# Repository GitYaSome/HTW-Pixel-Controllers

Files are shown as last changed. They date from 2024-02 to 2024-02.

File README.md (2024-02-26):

# HTW Pixel Controllers



I originally wanted to create these controllers as a gift for my fellow Warriors so that every HTW participant in any parade or night ride could have a high-quality set of LED lights.  On February 5th, 2024 I found out about Terry Sague being hit and killed by a car.  Other cyclists he was with were hospitalized.  That was yet another reason to get these done sooner rather than later.

Basic Use:
1.	Plug USB cord into trike battery or USB Powerbank.
2.	Press the power switch on the side of the USB Powerbank.
3.	Turn on the controller via the toggle switch. (It will default to 4th of July / Red, White, and Blue)
4.	Select a preset by pressing preset button – I programmed 5 presets into them:

a)	4th of July – Red, White, & Blue – (Default when the controller is turned on)
b)	Christmas – Red & Green
c)	Multicolor – Multicolor cycle – Alternate for Christmas
d)	Night Ride – Red, White, & Orange
e)	Maintenance – All White – Use for fixing something on your trike in the dark.

Notes:
1.	Unfortunately, the power switches I got from China are not as moisture proof as I thought and can get oxidation on the contacts.  If after doing steps 1-3 above the controller does not turn on, rapidly turn the power switch on and off about 10-20 times to clean the contacts.  (I added 2 silica gel packs to the 3D printed cases and used form-a-gasket to seal the lids on, so hopefully this won’t be an issue.)
2.	The white USB-A to USB-C cable in the accessory bag is to charge the USB Powerbanks.  The USB-C connectors on the USB Powerbanks are VERY delicate – PLEASE BE VERY CAREFUL INSERTING AND REMOVING THOSE CABLES.
In case anyone ever needs to make more or needs to troubleshoot, etc..

1.	3D Printed Case design files
2.	Circuit board schematics, Pick&Place, Gerber Files, & BOM
3.	Parts lists
4.	Extra Pictures

I hope you enjoy using these as much as I enjoyed making them for you – Have fun!!!
-Kevin Cook

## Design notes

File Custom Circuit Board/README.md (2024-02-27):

There are 3 files in this folder:
  1. BOM_HTW WLED PCB_2023-12-21.csv - This is the Bill of Materials file that contains part numbers for the assembly service to know what parts are needed.
  2. Gerber_HTW WLED PCB.zip - This is the file that has the board dimensions, locations of holes to be drilled, and schematic diagram. 
  3. PickAndPlace_HTW WLED PCB_2023-12-21.csv - This is the file that tells the assembly service the X and Y coordinates of where to place parts.

Those 3 files are what you would send to a Printed Circuit Board manufacturer (I use JLCPCB) to have PCB's made.
In addition to those 3 files, here are some pictures:

Schematic Diagram:


Circuit Board Layout:
Circuit Board Layout

Circuit Board Front View:
Circuit Board Front View

Circuit Board Rear View:
Circuit Board Rear View

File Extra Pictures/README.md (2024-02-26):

Extra Pictures:

Original prototype on a breadboard (This was mostly to test the level shifter):


From prototype to custom circuit board (Not all parts are soldered on here yet, but you get the idea):


ESP32 Microcontrollers ready to be flashed (Programmed):


Some 3D Printed cases:


Some 3D Printed Lids and Tube Mounts:


Lids done:


3d Printed Inserts:                                                


3D printed Lids with RED, White, and Blue inserts:


3D Printed End Caps for the Pixel Strings:                                                 


Waterproofing backs of inserts with liquid electrical tape:


Backs sealed up, ready for assembly:


Close up of some of the parts:


Getting there!:


A completed controller:


Form-a-gasket around the inner rim and all 4 screw posts:


2 packs of Silica Gel in each case:


Lid ready for bolts:


Red, White, and Blue Zipties inserted:


Ready for burn in test!


Burn in test:




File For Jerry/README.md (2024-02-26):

The controllers can all work in multiple ways:

1. 100% Stand Alone - Everyone responsible for their own.
   Each person will turn their controller on and select a preset.

2. Jerry Controls everyone via handheld remote.
   If there are about 12 controllers or less (We can test this in real world conditions once handed out) you can use the Wiz remote to turn everyone on / off and select 1 of the first 4 presets.
   Note - This is a software on / off - They will still all have to have their power swithches set to On at their individual controllers.

3. More than 12 riders via the Wiz remote or if you want to use the WLED App.
   Pack the included Wi-Fi router with you, and turn it on.  Then have each rider turn their controller on - They will all connect to this router and your controller is set to be the master controller - Whatever you do on yours, theirs will sync to it.
   Note - Your controller is HTW01 and has a special yellow heat shrink on the data cable to help differentiate it from the others.

4. If you are ever asked fo any password on the router or in the WLED app, the password is Warr10r5!

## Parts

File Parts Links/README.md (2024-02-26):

Parts Links:

50 Strand Bullet Pixels:
No mater where you buy them or what spacing you use, make sure you get WS281x, 5VDC, xConnect pinout (Many different pinouts are out there and if you put voltage into the data line, at a minimum you will kill the first pixel and have to cut it out and splice the cuts.) I ordered 2 strands of 50 for each controller with 6 inch spacing.



  https://www.aliexpress.us/item/3256805872144854.html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 (RayWu is a great seller - I used him for thousands of strands of lights when I did my Christmas light shows.)

USB Powerbank:
  https://www.amazon.com/gp/product/B07XFBN7HX/ref=ppx_yo_dt_b_search_asin_title?ie=UTF8&th=1

PG-11 Cable Glands:
  https://www.aliexpress.us/item/2255800056118195.html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

Stainless Steel Bolts:
  https://www.aliexpress.us/item/3256801789306671.html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

200cm USB Power Cables:
  https://www.aliexpress.us/item/3256805002233217.html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

Pixel Connector Cables:
  https://www.holidaycoro.com/EasyPlug3-Female-Pigtail-Dangle-xConnect-p/723-f.htm 

Switches:

MTS-202 Power Switches:
  https://www.aliexpress.us/item/2255800227673206.html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

Preset Select:
  https://www.aliexpress.us/item/3256802598843527.html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

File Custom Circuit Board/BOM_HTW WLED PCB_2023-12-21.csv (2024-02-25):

ID | Name | Designator | Footprint | Quantity | Manufacturer Part | Manufacturer | Supplier | Supplier Part | Price | Pins | 3DModel | Contributor | JLCPCB Part Class | Resistance (Ohms) | link
1 | HEADER - 2.54_1X5 | H1,H2 | HEADER-HEADER-FEMALE-2.54_1X5 | 2 |  |  |  |  |  | 5 |  | feelafter
2 | HEADER-1X2 FAN | X2,X1 | HEADER-1X2-2.54 | 2 |  |  | Mouser | undefined |  | 2 |  | sfzhi
3 | 4.7kΩ | R2,R3 | R0603 | 2 | 0603WAF4701T5E | UNI-ROYAL(厚声) | LCSC | C23162 | 0.001 | 2 | R0603 | lcsc | Basic Part | 4.7K | https://www.mouser.in/datasheet/2/447/PYu_RT_1_to_0_01_RoHS_L_11-1669912.pdf
4 | 10kΩ | R4 | R0603 | 1 | 0603WAF1002T5E | UNI-ROYAL(厚声) | LCSC | C25804 | 0.001 | 2 | R0603 | lcsc | Basic Part |  | https://lcsc.com/eda_search?q=C25804&%26type=1&ref=editor
5 | TLC-NSMD100 | U8,U9 | F1206 | 2 | TLC-NSMD100 | TLC(竞沃) | LCSC | C261954 | 0.06 | 2 | F1206_L3.2-W1.7-H0.6 | LCSC | Extended Part |  | https://atta.szlcsc.com/upload/public/pdf/source/20200518/C553934_4CFF0660EAE88BF7A646763F248900C5.pdf
6 | 3_PADS | U7 | PADPAD-3P (90X125) | 1 |  |  |  |  |  | 3 |  | forrestsundquist
7 | 100nF | C2 | C0603 | 1 | 0603ZC104KAT2A | Kyocera AVX | LCSC | C597251 | 0.027 | 2 | C0603_L1.6-W0.8-H0.8 | LCSC | Extended Part |  | https://item.szlcsc.com/362304.html
8 | Header-Female-2.54_2x10 | P1,P2 | HDR-TH_20P-P2.54-V-F-R2-C10-S2.54 | 2 | 2.54-2*10P母 | BOOMELE(博穆精密) | LCSC | C30867 | 0.16 | 20 | HDR-TH_20P-P2.54-F-LI-2X10P | lcsc | Extended Part |  | https://item.szlcsc.com/760101.html
9 | 1000uF | C1 | CAP-TH_BD8.0-P3.50-D0.6-FD | 1 | RC010M102LO8*12TH-2A1E | BERYL(绿宝石) | LCSC | C357594 | 0.065 | 2 | CAP-TH_D8.0-H8.0-P3.50 | LCSC | Extended Part |  | https://lcsc.com/eda_search?q=C357594&%26type=1&ref=editor
10 | KF301-5.0-2P | U4,U5 | CONN-TH_P5.00_KF301-5.0-2P | 2 | KF301-5.0-2P | KEFA(科发) | LCSC | C474881 | 0.09 | 2 | CONN-TH_P5.00_KF301-5.0-2P | LCSC | Extended Part |  | https://item.szlcsc.com/481499.html
11 | KF301-5.0-3P | U6 | CONN-TH_3P-P5.00_KF301-5.0-3P | 1 | KF301-5.0-3P | KEFA(科发) | LCSC | C474882 | 0.135 | 3 | CONN-TH_3P-P5.00_KF301-5.0-3P | LCSC | Extended Part |  | https://item.szlcsc.com/481500.html
12 | 100Ω | R1 | R0603 | 1 | 0603WAF1000T5E | UNI-ROYAL(厚声) | LCSC | C22775 | 0.001 | 2 | R0603 | lcsc | Basic Part |  | https://lcsc.com/eda_search?q=C22775&%26type=1&ref=editor
13 | TSOP38238 | LED1 | SENSOR-TG_TSOP38236 | 1 |  |  |  |  |  | 3 | SENSOR-TG_TSOP38236 | LCSC |  |  | https://lcsc.com/eda_search?q=C141632&%26type=1&ref=editor
14 | ESP32 | U2 | ESP32 MINIKIT | 1 |  |  |  |  |  | 40 |  | rimariot
15 | SN74AHCT125DR | U3 | SOIC-14_L8.7-W3.9-P1.27-LS6.0-BL | 1 | SN74AHCT125DR | TI(德州仪器) | LCSC | C155176 | 0.198 | 14 | SOIC-14_L8.6-W3.9-H1.8-LS6.0-P1.27 | LCSC | Extended Part |  | https://lcsc.com/eda_search?q=C155176&%26type=1&ref=editor

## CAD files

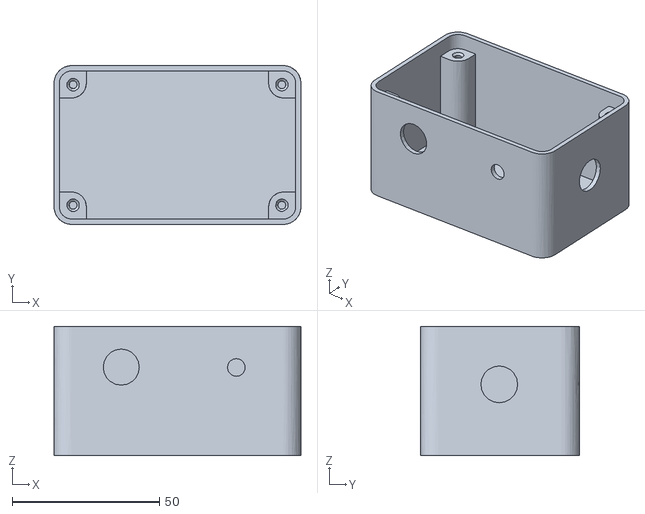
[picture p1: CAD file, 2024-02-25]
3D Printed Case/HTW Case.stl
84.0 x 54.0 x 44.0

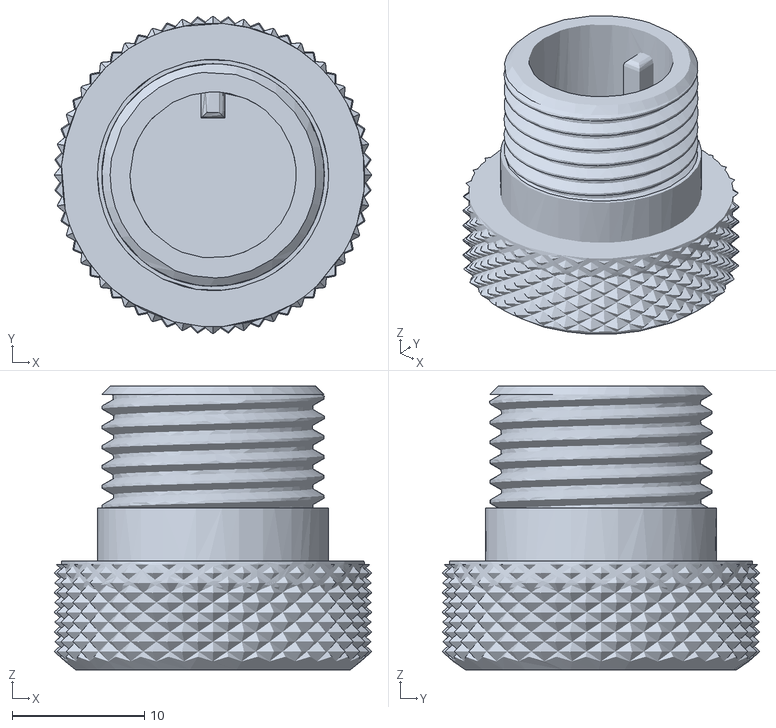
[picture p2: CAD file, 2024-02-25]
3D Printed Endcap/HTW Endcap.stl
24.0 x 24.0 x 21.5

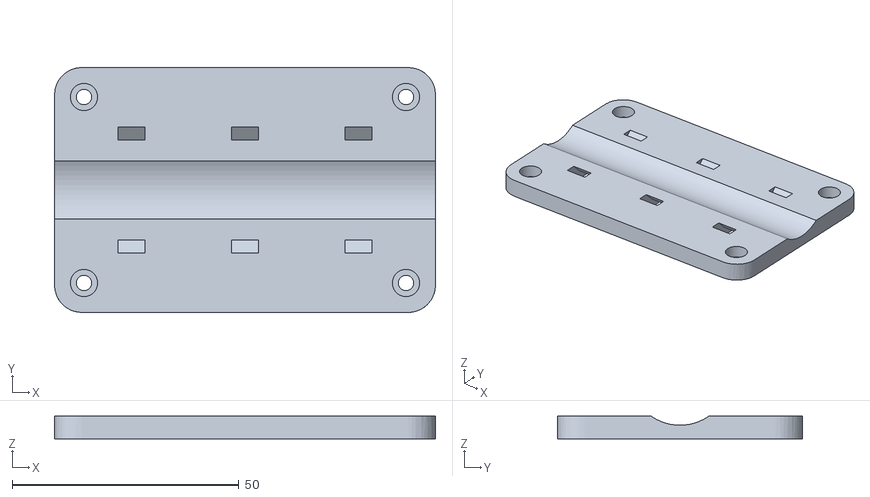
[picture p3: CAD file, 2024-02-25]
3D Printed Case/HTW Mount-875inch.stl
84.0 x 54.0 x 5.00

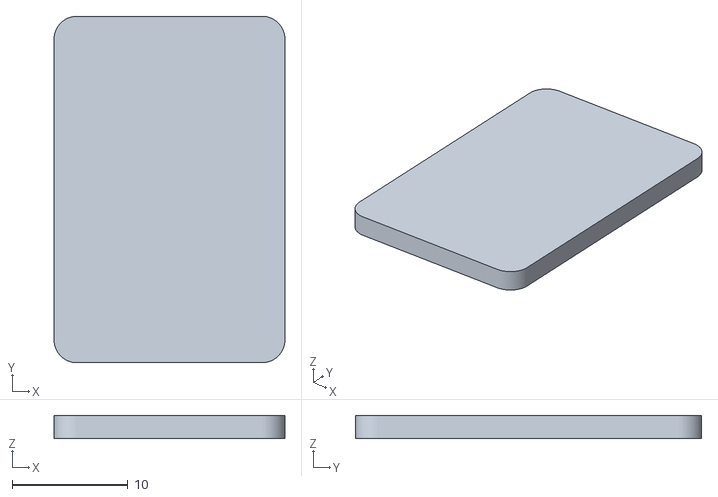
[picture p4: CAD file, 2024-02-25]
3D Printed Case/HTW Insert.stl
20.0 x 30.0 x 2.00

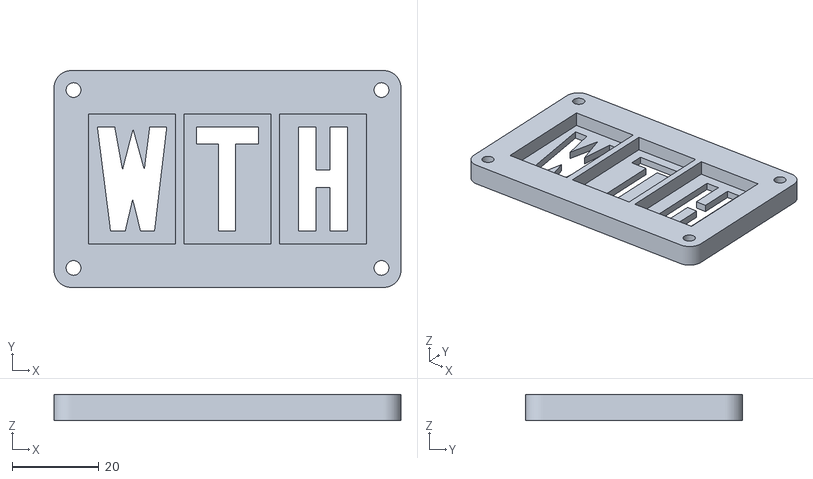
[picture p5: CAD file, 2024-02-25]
3D Printed Case/HTW Lid.stl
80.0 x 50.0 x 6.00

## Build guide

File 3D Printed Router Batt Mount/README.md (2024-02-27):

This folder contains the 3D printable files for the router battery mount.

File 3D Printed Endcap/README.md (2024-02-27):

This folder has 1 file - HTW Endcap.stl
It is the 3D printable endcap for the end of the pixel strands.

Pictures:





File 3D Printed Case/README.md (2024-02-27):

This folder contains the 3D printable files for the case, lid, inserts, and back mounting bracket.

Pictures:

Case:



Insert (Print 1 red, 1 white and 1 blue):



Lid:





Mount:





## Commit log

2024-02-25 Create 3D Printed Case
2024-02-25 Update 3D Printed Case
